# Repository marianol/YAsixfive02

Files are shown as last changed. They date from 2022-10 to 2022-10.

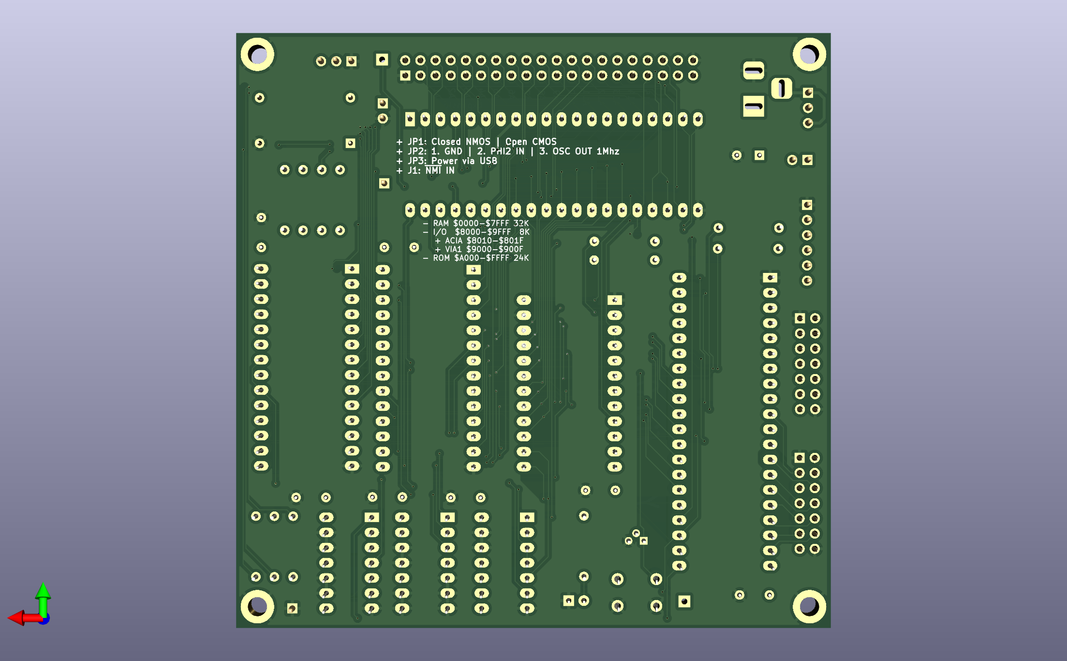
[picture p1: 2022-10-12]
YAsixfive02_BACK.png

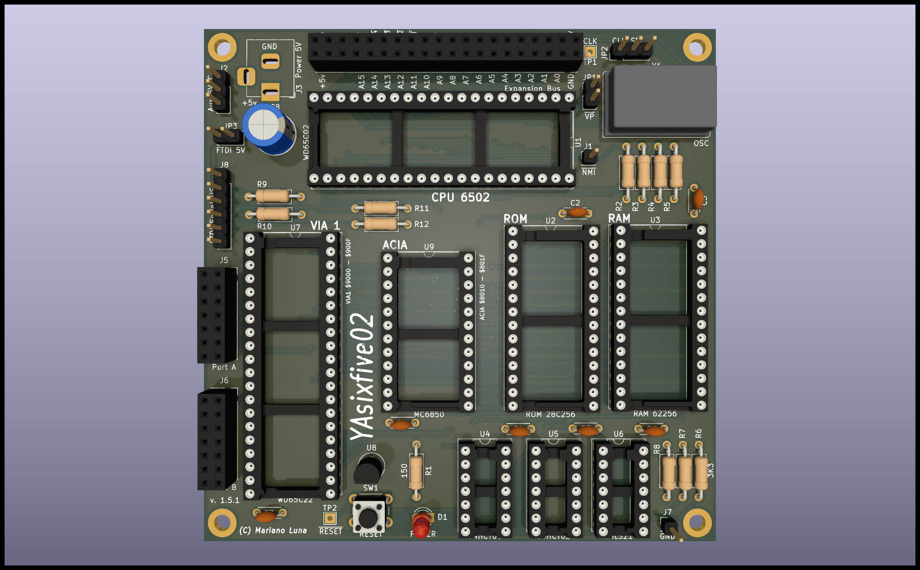
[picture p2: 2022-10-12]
YAsixfive02_FRONT.png

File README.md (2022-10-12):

# YAsixfive02 - Yet another 6502 SBC

Just my own take on a 6502 single board computer, inspired on Garth Wilson's excellent 6502 Primer, Daryl Rictor, Ben Eater, and my own beautiful C=64 and all the classic 8-bit computers of the laste 70s early 80s
This repository contains all the work in progress while I build my own SBC. So far I only have my PCB work here, more to come. 
I got tired of having a rat's nest of wires in breadboards and since I'm no wire-rapper I started with a basic PCB to hold CPU, Memory and ROM with a connector so I can start testing the "extras" like serial, VIA, etc.

Not that this is work in progress.. 

## References and Credits

This is my list of references and places where I have found most of the answers to my questions:

- [Ben Eater](https://eater.net) - his videos inspired me to start playing with electronicas again.
- [Garth Wilson's 6502 Primer](http://wilsonminesco.com/6502primer/) - Kudos sir, you have created the bible of 6502-SBC information.
- [Daryl Rictor](https://sbc.rictor.org/home.html) - great documentation on his projects and infinite wisdom in the 6505.org forum.
- [Grant Searle](http://searle.x10host.com/6502/Simple6502.html) - Great example and information on his simple 8 (or 7) chip 6502 SBC.
- And of course 6502.org, Reddit and all the people that share information that I find with google :)

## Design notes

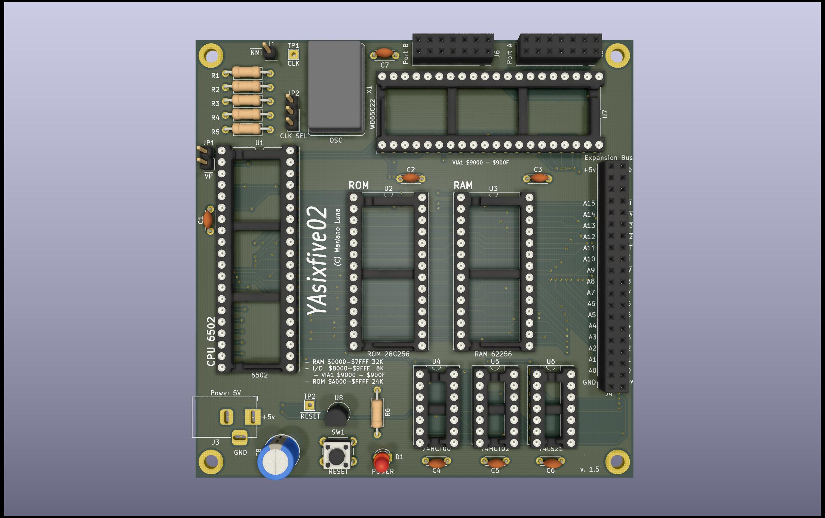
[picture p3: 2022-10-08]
YA6502_HiRes.jpg

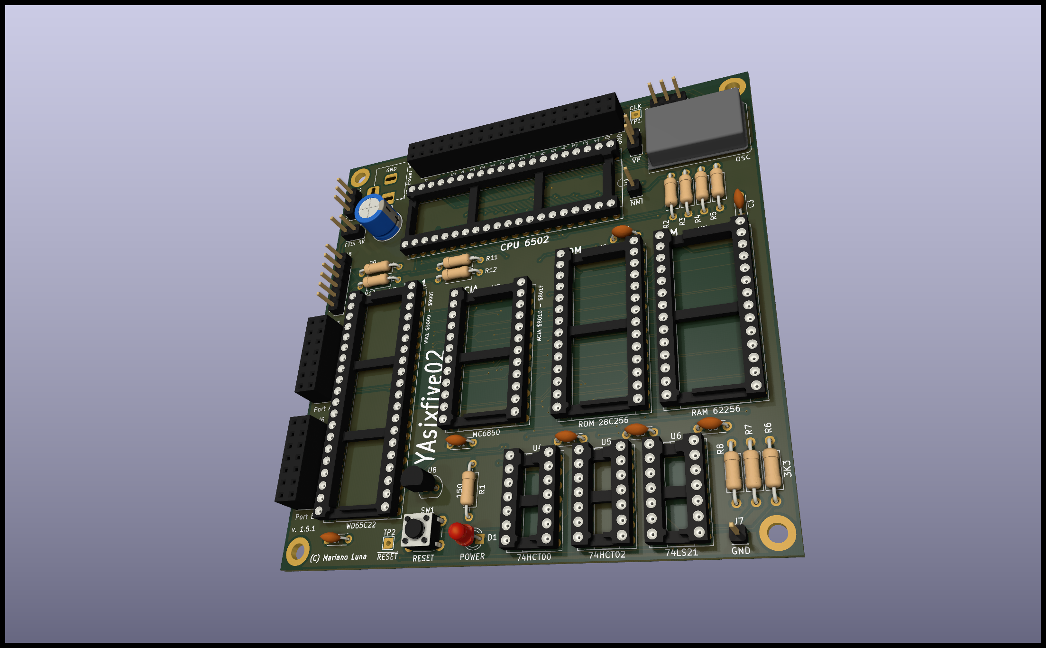
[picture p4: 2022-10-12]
YAsixfive02_Board.png

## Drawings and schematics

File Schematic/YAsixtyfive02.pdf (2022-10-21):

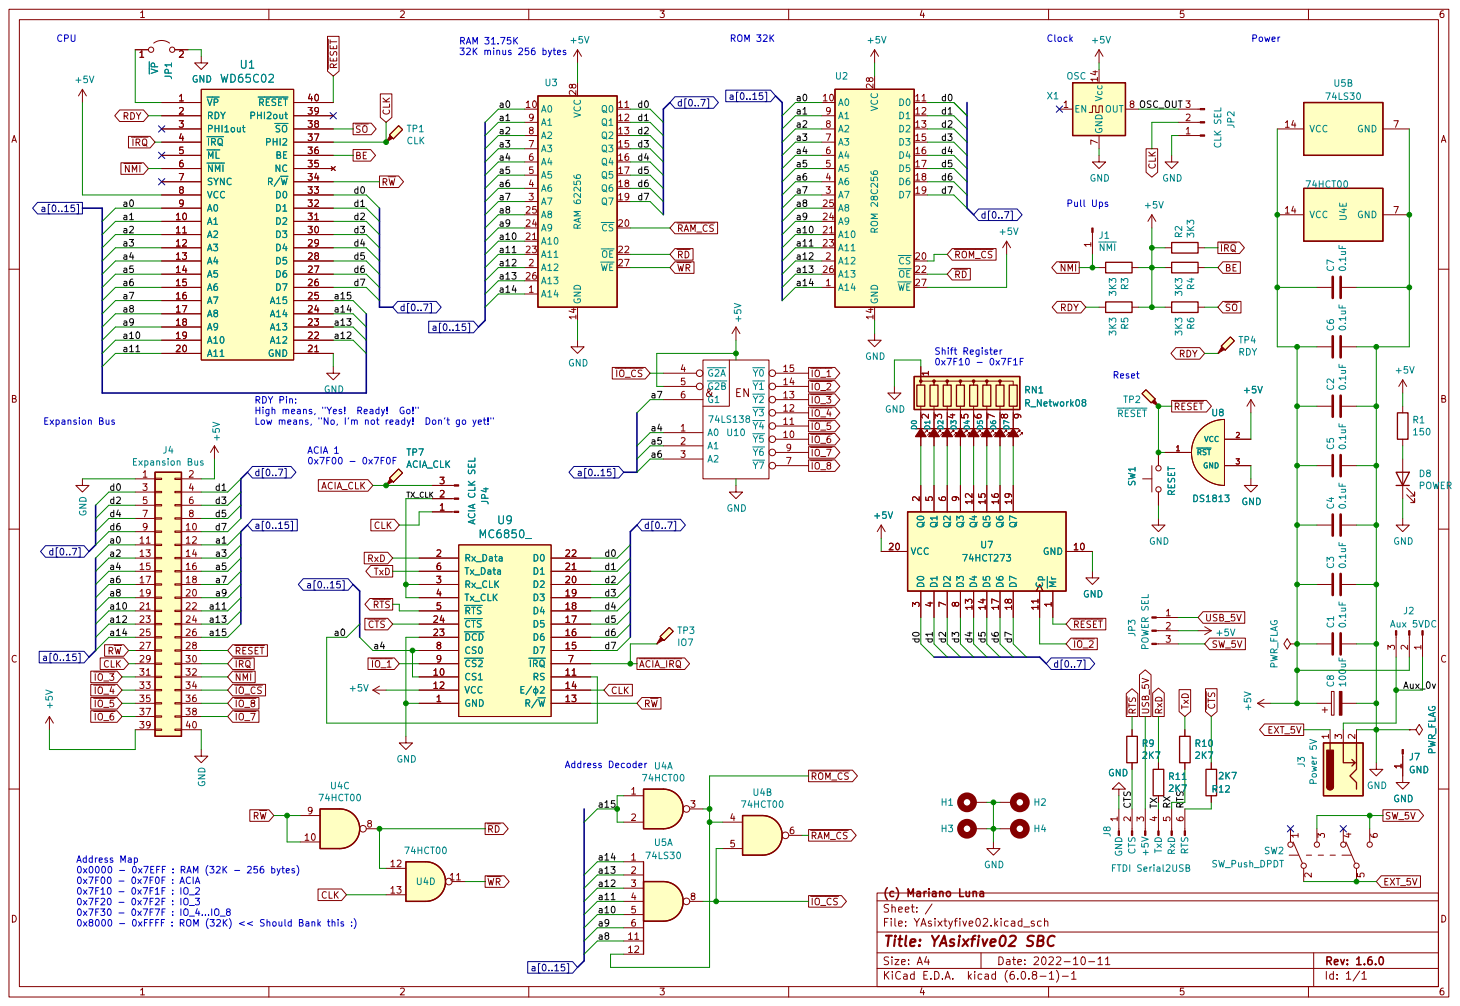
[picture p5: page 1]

32K minus 256 bytes RDY Pin: High means, "Yes! Ready! Go!"

Low means, "No, I'm not ready! Don't go yet!"

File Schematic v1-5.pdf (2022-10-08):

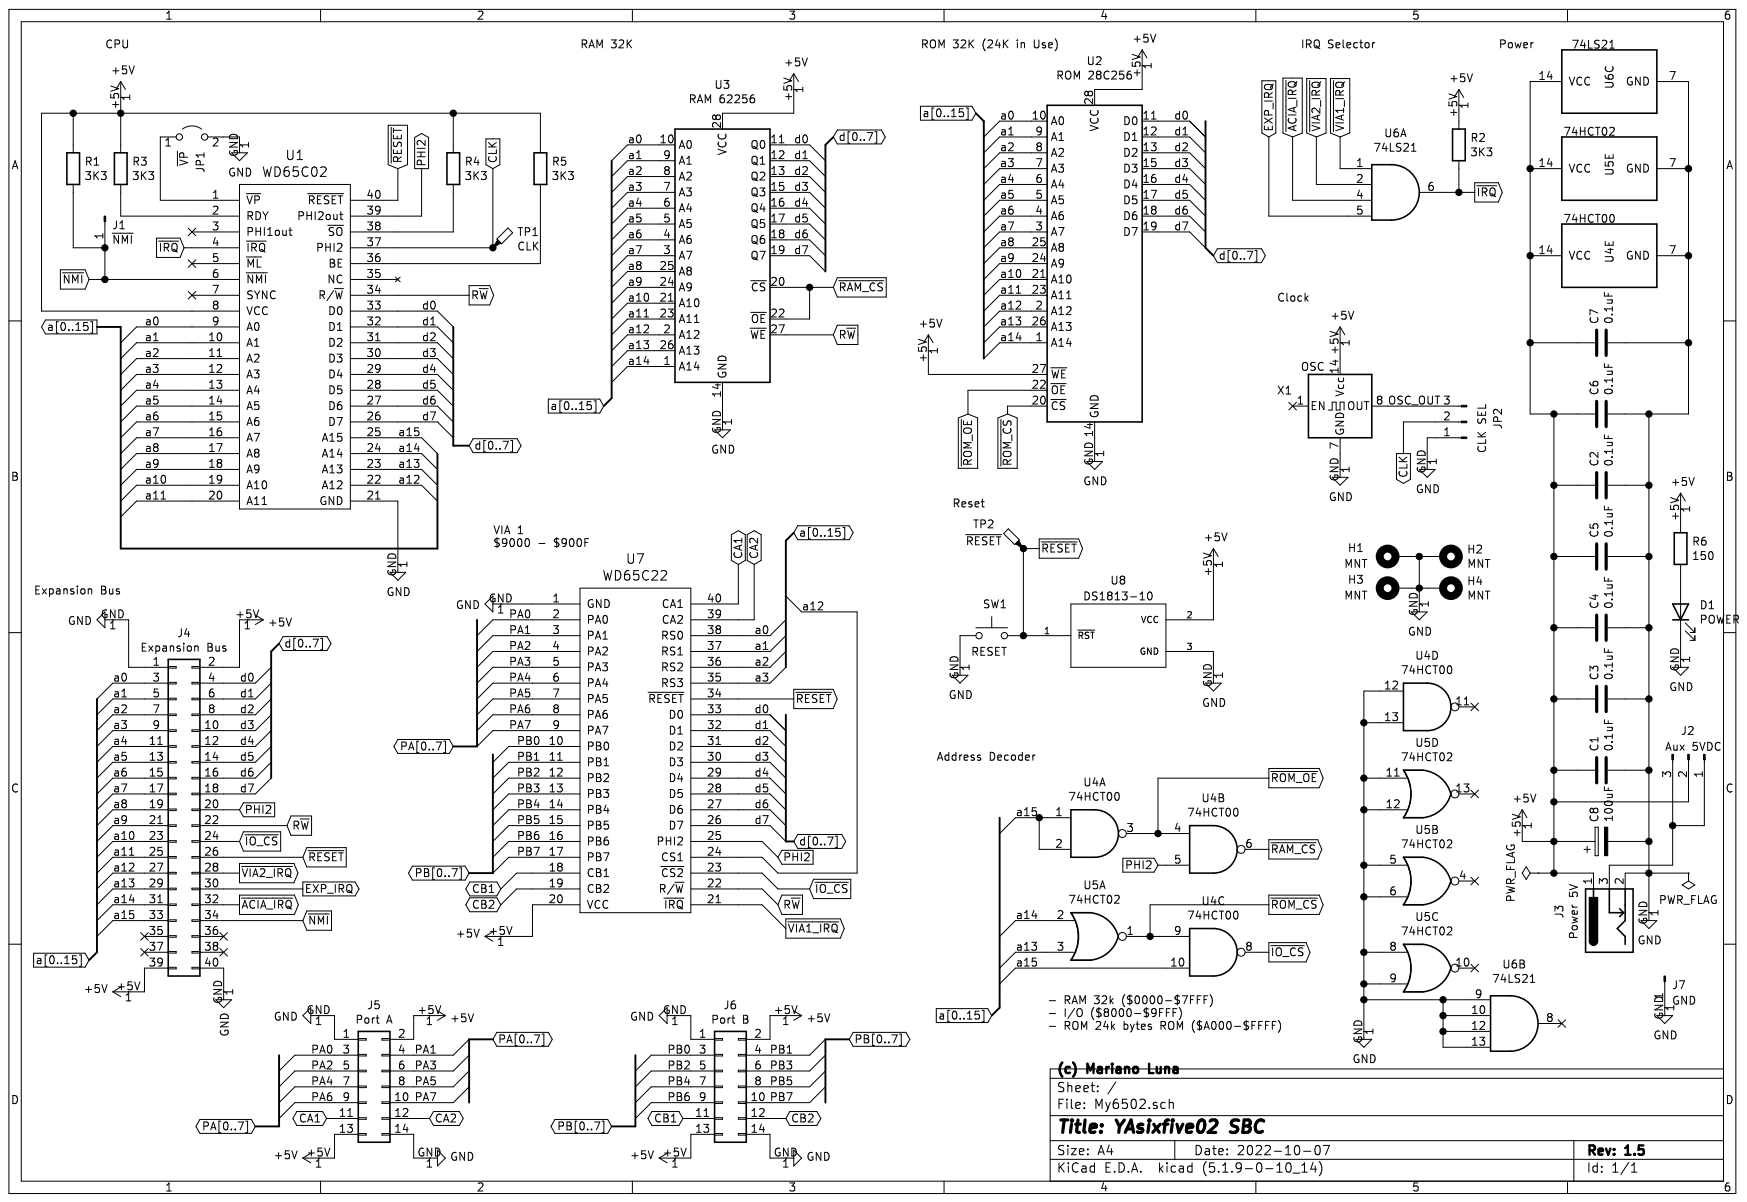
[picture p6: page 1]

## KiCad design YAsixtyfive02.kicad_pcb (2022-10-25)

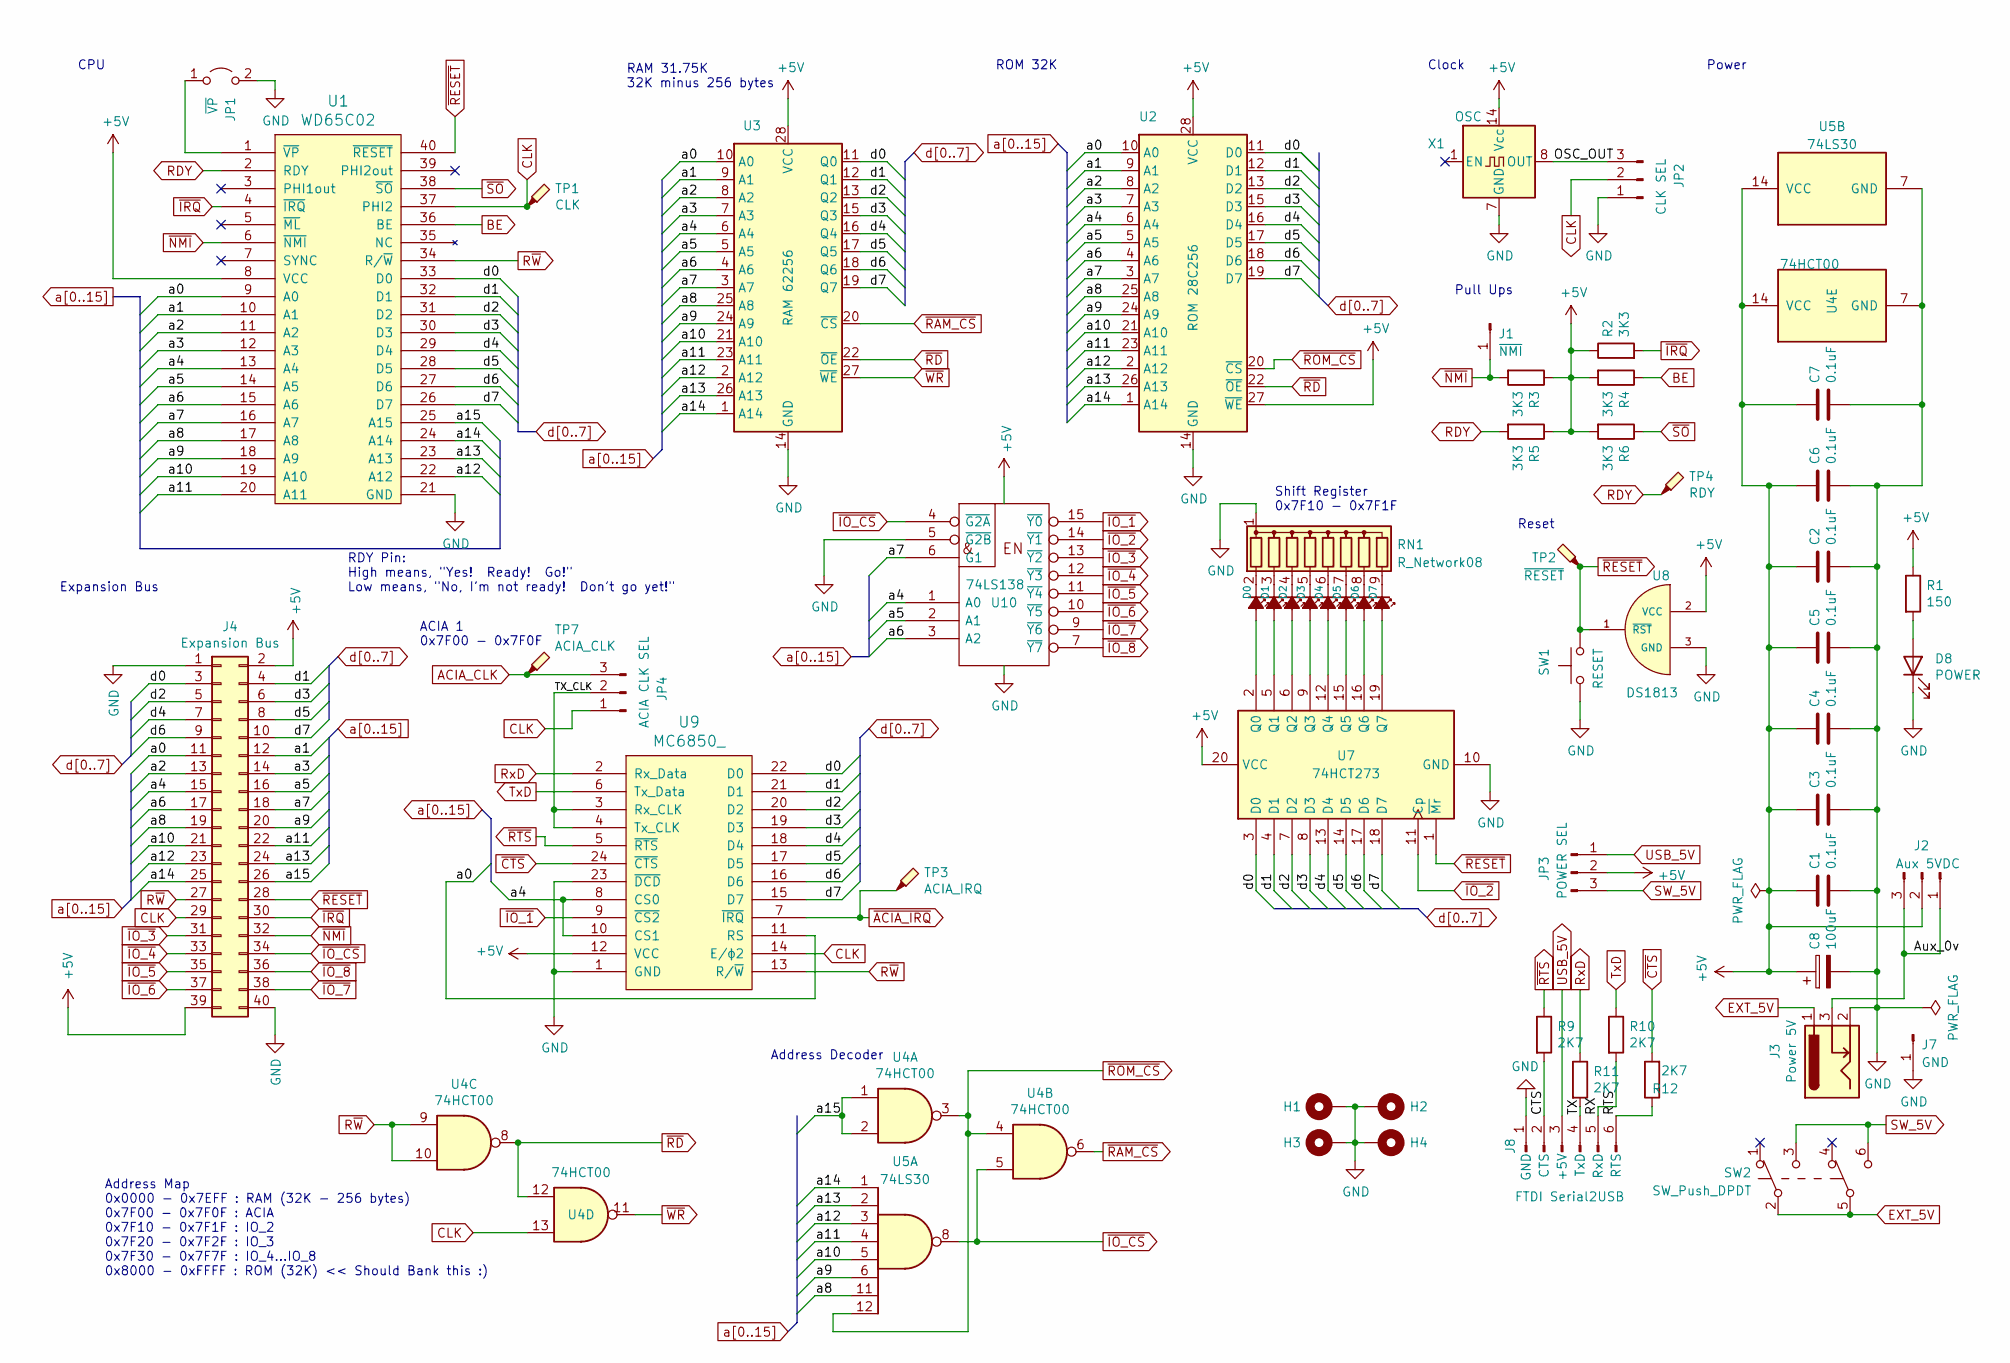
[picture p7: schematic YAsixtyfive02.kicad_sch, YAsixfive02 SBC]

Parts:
C1, C2, C3, C4, C5, C6, C7: 0.1uF; C_Disc_D4.3mm_W1.9mm_P5.00mm
C8: 100uF; CP_Radial_D6.3mm_P2.50mm
D0: CTL_0; LED_D3.0mm
D1: CTL_1; LED_D3.0mm
D2: CTL_2; LED_D3.0mm
D3, D4, D5, D6, D7: 3; LED_D3.0mm
D8: POWER; LED_D3.0mm
H1, H2, H3, H4: MNT; MountingHole_3.2mm_M3_DIN965_Pad_TopBottom
J1: ~{NMI}; PinHeader_1x01_P2.54mm_Vertical
J2: Aux 5VDC; PinHeader_1x03_P2.54mm_Vertical
J3: Power 5V; BarrelJack_Horizontal
J4: Expansion Bus; PinSocket_2x20_P2.54mm_Vertical
J7: GND; PinHeader_1x01_P2.54mm_Vertical
J8: FTDI Serial2USB; PinHeader_1x06_P2.54mm_Vertical
JP1: ~{VP}; PinHeader_1x02_P2.54mm_Vertical
JP2: CLK SEL; PinHeader_1x03_P2.54mm_Vertical
JP3: POWER SEL; PinHeader_1x03_P2.54mm_Vertical
JP4: ACIA CLK SEL; PinHeader_1x03_P2.54mm_Vertical
R1: 150; R_Axial_DIN0207_L6.3mm_D2.5mm_P10.16mm_Horizontal
R2, R3, R4, R5, R6: 3K3; R_Axial_DIN0207_L6.3mm_D2.5mm_P10.16mm_Horizontal
R9, R10, R11, R12: 2K7; R_Axial_DIN0207_L6.3mm_D2.5mm_P10.16mm_Horizontal
RN1: R_Network08; R_Array_SIP9
SW1: RESET; SW_PUSH_6mm_H5mm
SW2: SW_Push_DPDT; SW_NKK_GW12LJP
TP1: CLK; TestPoint_THTPad_1.5x1.5mm_Drill0.7mm
TP2: ~{RESET}; TestPoint_THTPad_1.5x1.5mm_Drill0.7mm
TP3: ACIA_IRQ; TestPoint_THTPad_1.0x1.0mm_Drill0.5mm
TP4: RDY; TestPoint_THTPad_1.0x1.0mm_Drill0.5mm
TP7: ACIA_CLK; TestPoint_THTPad_1.5x1.5mm_Drill0.7mm
U1: WD65C02; DIP-40_W15.24mm_Socket_LongPads
U2: ROM 28C256; DIP-28_W15.24mm_Socket_LongPads
U3: RAM 62256; DIP-28_W15.24mm_Socket_LongPads
U4: 74HCT00; DIP-14_W7.62mm_Socket_LongPads
U5: 74LS30; DIP-14_W7.62mm_Socket_LongPads
U7: 74HCT273; DIP-20_W7.62mm_Socket_LongPads
U8: DS1813; TO-92; MANUFACTURER_PART_NUMBER ds181315+
U9: MC6850_; DIP-24_W15.24mm_Socket_LongPads
U10: 74LS138; DIP-16_W7.62mm_Socket_LongPads
X1: OSC; Oscillator_DIP-14

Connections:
+5V: C1.1, C2.1, C3.1, C4.1, C5.1, C6.1, C7.1, C8.1, J2.2, J4.2, J4.39, JP3.2, R1.1, R2.1, R3.1, R4.2, R5.1, R6.2, U1.8 (VCC), U2.27 (~WE), U2.28 (VCC), U3.28 (VCC), U4.14 (VCC), U5.14 (VCC), U7.20 (VCC), U8.2 (VCC), U9.12 (VCC), U10.16 (VCC), X1.14 (Vcc)
/Aux_0v: J2.1, J2.3, J3.3
/CTS: J8.2 (CTS), R9.2
/OSC_OUT: JP2.3, X1.8 (OUT)
/RTS: J8.6 (RTS), R12.1
/RX: J8.5 (RxD), R10.2
/TX: J8.4 (TxD), R11.2
/TX_CLK: JP4.2, U9.3 (Rx_CLK), U9.4 (Tx_CLK)
ACIA_CLK: JP4.3, TP7.1
BE: R4.1, U1.36 (BE)
CLK: J4.29, JP2.2, JP4.1, TP1.1, U1.37 (PHI2), U4.13, U9.14 (E/ϕ2)
EXT_5V: J3.1, SW2.2 (B), SW2.5 (B)
GND: C1.2, C2.2, C3.2, C4.2, C5.2, C6.2, C7.2, C8.2, D8.1 (K), H1.1, H2.1, H3.1, H4.1, J3.2, J4.1, J4.40, J7.1, J8.1 (GND), JP1.2 (B), JP2.1, RN1.1 (common), SW1.1, U1.21 (GND), U2.14 (GND), U3.14 (GND), U4.7 (GND), U5.7 (GND), U7.10 (GND), U8.3 (GND), U9.1 (GND), U9.23 (~DCD), U10.5 (~G2B), U10.8 (GND), X1.7 (GND)
unnamed: D0.1 (K), RN1.2 (R1)
unnamed: D0.2 (A), U7.2 (Q0)
unnamed: D1.1 (K), RN1.3 (R2)
unnamed: D1.2 (A), U7.5 (Q1)
unnamed: D2.1 (K), RN1.4 (R3)
unnamed: D2.2 (A), U7.6 (Q2)
unnamed: D3.1 (K), RN1.5 (R4)
unnamed: D3.2 (A), U7.9 (Q3)
unnamed: D4.1 (K), RN1.6 (R5)
unnamed: D4.2 (A), U7.12 (Q4)
unnamed: D5.1 (K), RN1.7 (R6)
unnamed: D5.2 (A), U7.15 (Q5)
unnamed: D6.1 (K), RN1.8 (R7)
unnamed: D6.2 (A), U7.16 (Q6)
unnamed: D7.1 (K), RN1.9 (R8)
unnamed: D7.2 (A), U7.19 (Q7)
unnamed: D8.2 (A), R1.2
unnamed: JP1.1 (A), U1.1 (~VP)
RDY: R5.2, TP4.1, U1.2 (RDY)
RxD: R11.1, U9.2 (Rx_Data)
R~W: J4.27, U1.34 (R/~W), U4.9, U4.10, U9.13 (R/~W)
SW_5V: JP3.3, SW2.3 (C), SW2.6 (C)
TxD: R10.1, U9.6 (Tx_Data)
USB_5V: J8.3 (+5V), JP3.1
a0: J4.11, U1.9 (A0), U2.10 (A0), U3.10 (A0), U9.11 (RS)
a1: J4.12, U1.10 (A1), U2.9 (A1), U3.9 (A1)
a2: J4.13, U1.11 (A2), U2.8 (A2), U3.8 (A2)
a3: J4.14, U1.12 (A3), U2.7 (A3), U3.7 (A3)
a4: J4.15, U1.13 (A4), U2.6 (A4), U3.6 (A4), U9.8 (CS0), U9.10 (CS1), U10.1 (A0)
a5: J4.16, U1.14 (A5), U2.5 (A5), U3.5 (A5), U10.2 (A1)
a6: J4.17, U1.15 (A6), U2.4 (A6), U3.4 (A6), U10.3 (A2)
a7: J4.18, U1.16 (A7), U2.3 (A7), U3.3 (A7), U10.6 (G1)
a8: J4.19, U1.17 (A8), U2.25 (A8), U3.25 (A8), U5.11
a9: J4.20, U1.18 (A9), U2.24 (A9), U3.24 (A9), U5.6
a10: J4.21, U1.19 (A10), U2.21 (A10), U3.21 (A10), U5.5
a11: J4.22, U1.20 (A11), U2.23 (A11), U3.23 (A11), U5.4
a12: J4.23, U1.22 (A12), U2.2 (A12), U3.2 (A12), U5.3
a13: J4.24, U1.23 (A13), U2.26 (A13), U3.26 (A13), U5.2
a14: J4.25, U1.24 (A14), U2.1 (A14), U3.1 (A14), U5.1
a15: J4.26, U1.25 (A15), U4.1, U4.2
d0: J4.3, U1.33 (D0), U2.11 (D0), U3.11 (Q0), U7.3 (D0), U9.22 (D0)
d1: J4.4, U1.32 (D1), U2.12 (D1), U3.12 (Q1), U7.4 (D1), U9.21 (D1)
d2: J4.5, U1.31 (D2), U2.13 (D2), U3.13 (Q2), U7.7 (D2), U9.20 (D2)
d3: J4.6, U1.30 (D3), U2.15 (D3), U3.15 (Q3), U7.8 (D3), U9.19 (D3)
d4: J4.7, U1.29 (D4), U2.16 (D4), U3.16 (Q4), U7.13 (D4), U9.18 (D4)
d5: J4.8, U1.28 (D5), U2.17 (D5), U3.17 (Q5), U7.14 (D5), U9.17 (D5)
d6: J4.9, U1.27 (D6), U2.18 (D6), U3.18 (Q6), U7.17 (D6), U9.16 (D6)
d7: J4.10, U1.26 (D7), U2.19 (D7), U3.19 (Q7), U7.18 (D7), U9.15 (D7)
~ACIA_IRQ: TP3.1, U9.7 (~IRQ)
~CTS: R12.2, U9.24 (~CTS)
~IO_1: U9.9 (~CS2), U10.15 (~Y0)
~IO_2: U7.11 (Cp), U10.14 (~Y1)
~IO_3: J4.31, U10.13 (~Y2)
~IO_4: J4.33, U10.12 (~Y3)
~IO_5: J4.35, U10.11 (~Y4)
~IO_6: J4.37, U10.10 (~Y5)
~IO_7: J4.38, U10.9 (~Y6)
~IO_8: J4.36, U10.7 (~Y7)
~IO_CS: J4.34, U4.5, U5.8, U10.4 (~G2A)
~IRQ: J4.30, R2.2, U1.4 (~IRQ)
~NMI: J1.1, J4.32, R3.2, U1.6 (~NMI)
~RAM_CS: U3.20 (~CS), U4.6
~RD: U2.22 (~OE), U3.22 (~OE), U4.8, U4.12
~RESET: J4.28, SW1.2, TP2.1, U1.40 (~RESET), U7.1 (~Mr), U8.1 (~RST)
~ROM_CS: U2.20 (~CS), U4.3, U4.4, U5.12
~RTS: R9.1, U9.5 (~RTS)
~SO: R6.1, U1.38 (~SO)
~WR: U3.27 (~WE), U4.11

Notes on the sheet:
Power
CPU
Clock
Expansion Bus
Pull Ups
ROM 32K
Reset
RDY Pin: High means, "Yes! Ready! Go!" Low means, "No, I'm not ready! Don't go yet!"
Address Decoder
RAM 31.75K 32K minus 256 bytes
Shift Register 0x7F10 - 0x7F1F
ACIA 1 0x7F00 - 0x7F0F
Address Map 0x0000 - 0x7EFF : RAM (32K - 256 bytes) 0x7F00 - 0x7F0F : ACIA 0x7F10 - 0x7F1F : IO_2 0x7F20 - 0x7F2F : IO_3 0x7F30 - 0x7F7F : IO_4...IO_8 0x8000 - 0xFFFF : ROM (32K) << Should Bank this :)

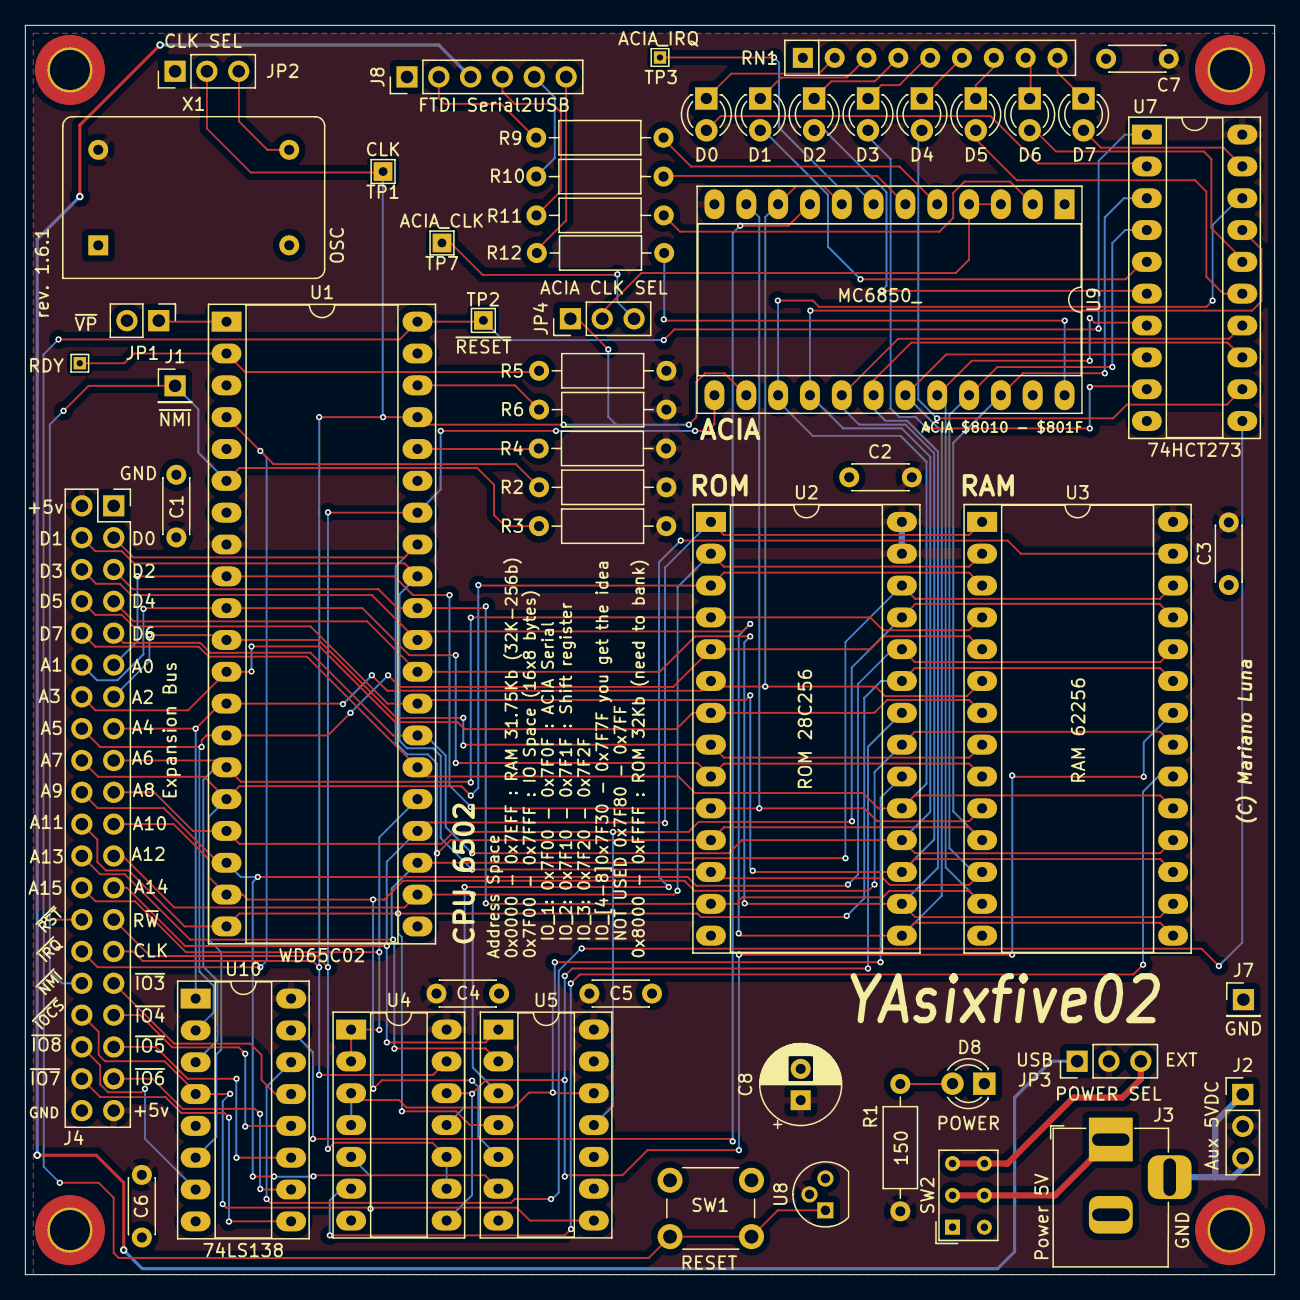
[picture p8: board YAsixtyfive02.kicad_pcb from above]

Board: 2 copper layers, 99.7 x 99.7 mm, 59 parts (0 on the bottom side), 81 nets.

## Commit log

2022-09-06 My6502 initial commit, full project witrh big board
    [My6502.dsn, My6502.kicad_pcb, My6502.sch]
2022-09-06 pcb with a 10x10 board`
    [My6502.kicad_pcb, My6502.sch]
2022-09-06 10 by 10 finished, gerber output ready
    [My6502-B_Cu.gbl, My6502-B_Mask.gbs, My6502-B_Paste.gbp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]
2022-09-06 correct board size to 99.69x99.69
    [My6502.kicad_pcb]
2022-09-06 Gerber Plot foles with new size
    [My6502-B_Cu.gbl, My6502-B_Mask.gbs, My6502-B_Paste.gbp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]
2022-09-06 gerber zip redy to send
2022-09-06 PCB Sent to manufacturing
    [My6502.kicad_pcb]
2022-09-08 Edge board completed and routed
    [My6502.kicad_pcb, My6502.sch]
2022-09-12 moving to a backplane
    [My6502.kicad_pcb, My6502.sch]
2022-09-12 Clean processor board schematic
    [My6502.sch]
2022-09-12 PCB completed CPU Board no clock
    [My6502.kicad_pcb]
2022-09-12 Rev 1 with silkscreen
    [My6502.kicad_pcb, My6502.sch]
2022-09-27 Update My6502.pro
    Printing Schematic, need to change 6502 footprint
2022-10-07 New Design with VIA1 on board - WIP
    [My6502.sch]
2022-10-07 Added power LED
    [My6502.sch]
2022-10-07 Components Placed - missing wiring the VIA
    [My6502.kicad_pcb, My6502.sch]
2022-10-07 PCB done minus VIA Registers - DRC Passing
    [My6502.kicad_pcb, My6502.sch]
2022-10-07 V1.5 Ready - Full board CPU,RAM,ROM,VIA
    [My6502.kicad_pcb, My6502.sch]
2022-10-07 Gerber files and Pictures v 1.5
    [My6502-B_Cu.gbl, My6502-B_Fab.gbr, My6502-B_SilkS.gbo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]
2022-10-07 Zipped Gerber added
2022-10-08 Gerber file deleted had errors. New Schematic with power leads and GND Test
    [My6502-B_Cu.gbl, My6502-B_Fab.gbr, My6502-B_Mask.gbs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]
2022-10-08 YAsicfive02 1.5 final version - Gerber file done
    [My6502-B_Cu.gbl, My6502-B_Fab.gbr, My6502-B_SilkS.gbo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]
2022-10-10 v1.5 complete with routed PCB.
2022-10-11 Added ACIA in schematic
    [My6502.sch]
2022-10-11 c1.5.2 schematic finished - error in U9 oin 23
    [My6502.sch]
2022-10-11 Schema ready v1.5.2 ACIA and VIA on
    [My6502.sch]
2022-10-11 PCB Component placement first take
    [My6502.kicad_pcb, My6502.sch]
2022-10-11 spring cleanning
2022-10-11 Updated to KiCad 6
    [My6502.kicad_pcb, YAsixtyfive02.kicad_pcb, YAsixtyfive02.kicad_sch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]
2022-10-12 PCB take 1 v1.5.2 Complete VIA + ACIA
    [YAsixtyfive02.kicad_pcb]
2022-10-12 Board cleanup, renders and add backups to gitignore
    [YAsixtyfive02.kicad_pcb]
2022-10-12 deleted old v5 files
    [My6502.dsn]
2022-10-12 adding schematic pdf - for real now
2022-10-19 changed PHI2 out to CLK and PCB tweaks
    [YAsixtyfive02.kicad_pcb, YAsixtyfive02.kicad_sch]
2022-10-21 Simplified board for backplane only CPU/RAM/ROM/ACIA/Glue
    [YAsixtyfive02.kicad_sch]
2022-10-21 copy of SCH with VIA/ACIA and glue
    [YAsixtyfive02_Decoder.kicad_sch]
2022-10-21 Schematic annotated and ERC pass
    [YAsixtyfive02.kicad_sch]
2022-10-21 Deleted unused gate, ERC passed
    [YAsixtyfive02.kicad_sch]
2022-10-21 Test Pads Footprint Changed
    [YAsixtyfive02.kicad_sch]
2022-10-21 COmponents placed ready to route
    [YAsixtyfive02.kicad_pcb, YAsixtyfive02.kicad_sch]
2022-10-21 PCB Almost ready missing USB Power override
    [YAsixtyfive02.kicad_pcb, YAsixtyfive02.kicad_sch]
2022-10-21 PCB Completed CPU/ACIA/RAM/ROM
    [YAsixtyfive02.kicad_pcb]
2022-10-21 Updated to a more efficient memory map
    Address Map
    0x0000 - 0x7EFF : RAM (32K - 256 bytes)
    0x7F00 - 0x7F0F : ACIA
    0x7F10 - 0x7F1F : IO_2
    0x7F20 - 0x7F2F : IO_3
    0x7F30 - 0x7F7F : IO_4...IO_8
    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
    [YAsixtyfive02.kicad_sch]
2022-10-21 rev 1.6.0 ready new memory map
    CPU/ROM/RAM/ACIA/SR New memory map, io in expansion port
    [YAsixtyfive02.kicad_pcb, YAsixtyfive02.kicad_sch]
2022-10-22 Clean up and minor PCB tweaks
    [My6502-B_Cu.gbl, My6502-B_Fab.gbr, My6502-B_SilkS.gbo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]
2022-10-24 monor routing revision clean DRC
    [YAsixtyfive02.kicad_pcb]
2022-10-25 rev 1.6.1 ready. minor routing updates and acia CS fixed.
    [YAsixtyfive02.kicad_pcb, YAsixtyfive02.kicad_sch]
